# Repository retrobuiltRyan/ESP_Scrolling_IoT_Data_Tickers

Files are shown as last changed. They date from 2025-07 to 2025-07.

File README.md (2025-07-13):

# ESP_Scrolling_IoT_Data_Tickers
ESP8266 (or ESP32) IoT data tickers for news, weather, stocks. For those classic looking 8x8 LED matrix modules. Custom ESP8266 Node MCU 12-E PCB (just bc i have a bunch of these dev boards I need to put to use to toss) with built-in buck converter (6-28V in) and SPI headers. PCB could use one more rev to address some quirks with the ESP8266's strapping pins (rotary encoder), but project is consider 'finished'.  
https://youtu.be/6R5AQ15R8a4

API's used:
api.weather.gov
https://newsapi.org/
finnhub.io

vlcsnap-2025-07-13-12h41m03s127



P1110438

PCB

| Reference | Value | Footprint | Qty | DNP  | DigiKey P/N |
|---|---|---|-----|---|---|
| BZ1 | Buzzer_5V | Buzzer_Beeper:MagneticBuzzer_ProSignal_ABT-410-RC | 1 | DNP | |
| C1,C3,C4,C5,C6 | 0.1uF 50V | Capacitor_SMD:C_1206_3216Metric | 5 | | 1276-1068-1-ND |
| C2,C7 | 0.22uF 50V CER | Capacitor_SMD:C_1206_3216Metric | 2 | | 445-2283-1-ND |
| D8 | D | Diode_SMD:D_SMC_Handsoldering | 1 | DNP  | S5AC-FDICT-ND |
| D9 | SMF15A | Diode_SMD:D_SMF | 1 | | SMF15A-E3-08CT-ND |
| J1 | Barrel_Jack | Connector_BarrelJack:BarrelJack_GCT_DCJ200-10-A_Horizontal | 1 | | EJ508A-ND |
| J2,J5,J6,J10 | Screw_Terminal_2_P3.50mm | TerminalBlock_Phoenix:PT-1,5-2-3.5-H_1x02_P3.50mm_Horizontal | 4 | |732-2747-ND|
| J3 | PINHD_1x5_Male | Connector_PinHeader_2.54mm:PinHeader_1x05_P2.54mm_Vertical | 1 | |  generic 0.1" breakaway header |
| J8 | PINHD_1x15_Male | Connector_PinHeader_2.54mm:PinHeader_1x15_P2.54mm_Vertical | 1 | | generic 0.1" breakaway header |
| Q1 | MOSFET P-CH 30V 25A TO252  | MOSFET_P-CH_30V_25A_TO252 | 1 | | 785-1106-1-ND |
| Q2 | MMBT2222A | Package_TO_SOT_SMD:SOT-23 | 1 | | MMBT2222ATPMSCT-ND |
| R1 | 220 | Resistor_SMD:R_1206_3216Metric | 1 | | 311-220FRCT-ND |
| R2,R3,R5,R6 | 1K | Resistor_SMD:R_1206_3216Metric | 4 | | 311-1.00KFRCT-ND |
| R4 | 3.3K | Resistor_SMD:R_1206_3216Metric | 1 | | 311-1.00KFRCT-ND |
| R7 | 100k | Resistor_SMD:R_1206_3216Metric | 1 | | 311-100KFRCT-ND |
| R8,R9,R10 | 10K | Resistor_SMD:R_1206_3216Metric | 3 | | 311-10.0KFRCT-ND |
| SW1 | RotaryEncoder_Switch_MP | Rotary_Encoder:RotaryEncoder_Alps_EC11E-Switch_Vertical_H20mm | 1 | DNP | PEC11R-4220F-S0024-ND |
| U1 | MAX40200AUK | Package_TO_SOT_SMD:SOT-23-5 | 1 | | 175-MAX40203AUK+TCT-ND |
| U2 | MP1584_Buck | MP1584 | 1 | [Aliexpress](https://www.aliexpress.us/item/3256806890547813.html) |
| U3 | L7805 | Package_TO_SOT_SMD:TO-252-2 | 1 |DNP | 497-7255-1-ND |

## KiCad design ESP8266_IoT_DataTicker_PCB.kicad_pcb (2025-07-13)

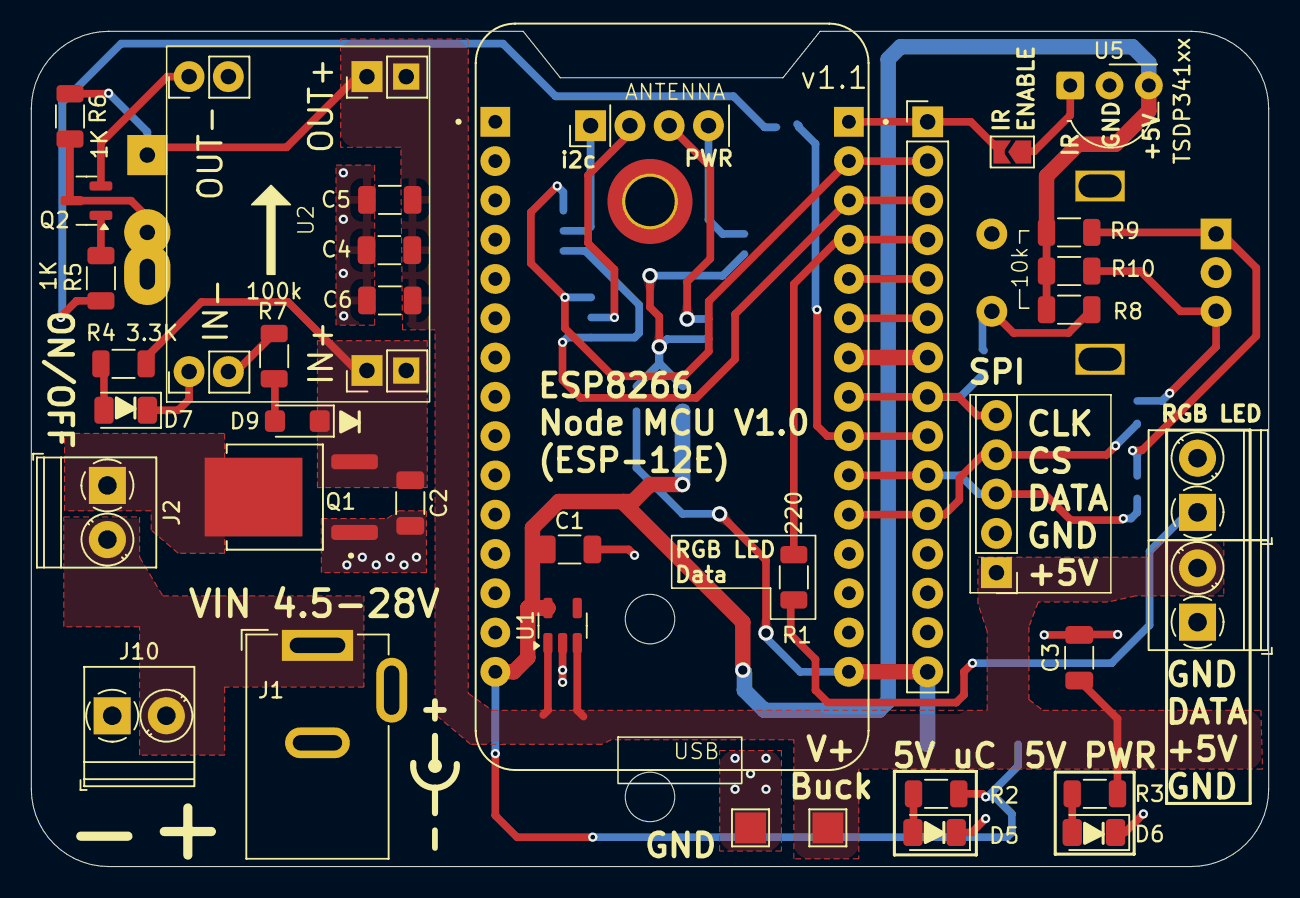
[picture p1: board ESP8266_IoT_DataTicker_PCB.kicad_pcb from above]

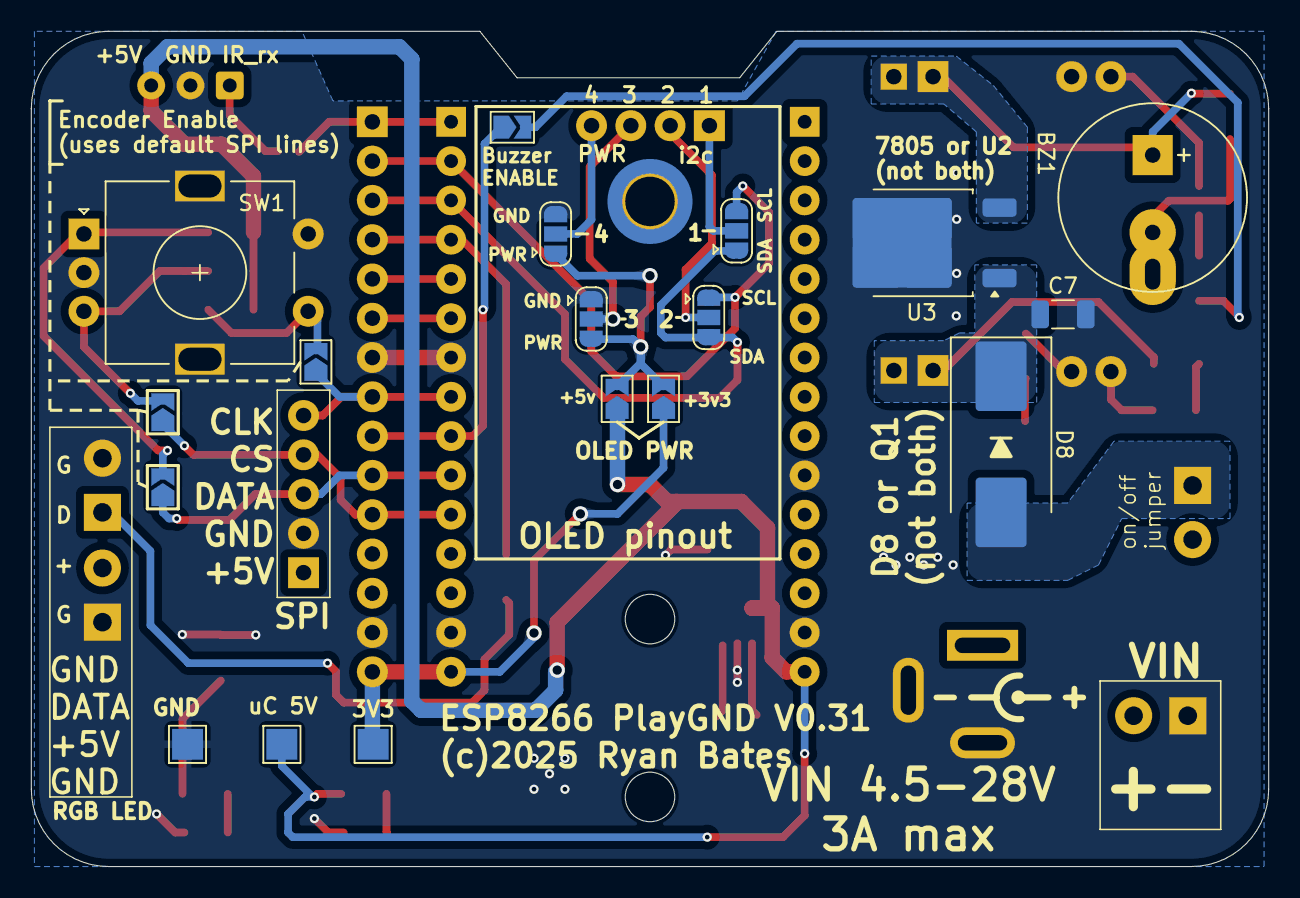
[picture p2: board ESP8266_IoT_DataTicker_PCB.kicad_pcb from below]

Board: 2 copper layers, 80.0 x 54.0 mm, 59 parts (18 on the bottom side), 34 nets.

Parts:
BZ1: Buzzer_5V; MagneticBuzzer_ProSignal_ABT-410-RC
C1, C3, C4, C5, C6: 0.1uF 50V; C_1206_3216Metric
C2, C7: 0.22uF 50V CER; C_1206_3216Metric
D5, D6, D7: LED; LED_1206_3216Metric
D8: D; D_SMC_Handsoldering
D9: SMF15A; D_SMF
H1: MountingHole; MountingHole_3.2mm_M3_ISO14580_Pad_TopBottom
H2, H3: MountingHole_M3; MountingHole_3.2mm_M3
J1: Barrel_Jack; BarrelJack_GCT_DCJ200-10-A_Horizontal
J2, J5, J6, J10: Screw_Terminal_2_P3.50mm; TerminalBlock_Phoenix_PT-1,5-2-3.5-H_1x02_P3.50mm_Horizontal
J3: PINHD_1x5_Male; PinHeader_1x05_P2.54mm_Vertical
J8: PINHD_1x15_Male; PinHeader_1x15_P2.54mm_Vertical
J9: PINHD_1x4_Male; PinHeader_1x04_P2.54mm_Vertical
JP1, JP3, JP5, JP6, JP9, JP10, JP11: SolderJumper_2_Open; SolderJumper-2_P1.3mm_Open_TrianglePad1.0x1.5mm
JP2, JP4, JP7, JP8: SolderJumper_3_Open; SolderJumper-3_P1.3mm_Open_RoundedPad1.0x1.5mm
Q1: MOSFET P-CH 30V 25A TO252; MOSFET_P-CH_30V_25A_TO252
Q2: MMBT2222A; SOT-23
R1: 220; R_1206_3216Metric
R2, R3, R5, R6: 1K; R_1206_3216Metric
R4: 3.3K; R_1206_3216Metric
R7: 100k; R_1206_3216Metric
R8, R9, R10: 10K; R_1206_3216Metric
SW1: RotaryEncoder_Switch_MP; RotaryEncoder_Alps_EC11E-Switch_Vertical_H20mm
TP1, TP3, TP4, TP6: uC +5V; TestPoint_Pad_2.0x2.0mm
TP2: 3V3; TestPoint_Pad_2.0x2.0mm
TP5: TestPoint; PinHeader_1x01_P1.00mm_Vertical
U1: MAX40200AUK; SOT-23-5
U2: MP1584_Buck; MP1584
U3: L7805; TO-252-2
U5: TSDP341xx; Vishay_MOLD-3Pin
v1.1: ESP8266; NodeMCU 12-E

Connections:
+5V_LED: BZ1.1, C3.1, C4.1, C5.1, C6.1, J3.1, J6.2, R3.1, R6.1, TP3.1, U1.1 (VDD), U1.3 (EN), U2.5 (OUT+), U2.6 (OUT+), U3.3 (OUT)
+BATT: J1.1, J2.2, J10.2
/1: J9.1, JP2.2 (C)
/2: J9.2, JP4.2 (C)
/3: J9.3, JP7.2 (C)
/3V3: J8.15, JP6.1 (A), TP2.1, v1.1.16 (3V3)
/4: J9.4, JP8.2 (C)
/BATT_IN: D8.2 (A), J2.1, Q1.2 (S)
/BATT_IN+: C2.1, C7.1, D8.1 (K), D9.1 (A1), Q1.3 (D), R4.1, U2.3 (IN+), U2.4 (IN+), U3.1 (IN)
/Buzzer: JP3.2 (B), R5.1
/D4(GPIO2): J8.5, v1.1.26 (D4)
/D6(GPIO12): J8.9, JP3.1 (A), v1.1.22 (D6)
/Encoder Button: JP11.2 (B), R8.1, SW1.S1
/Encoder CH_A: JP9.2 (B), R9.1, SW1.A
/Encoder CH_B: JP10.2 (B), R10.2, SW1.B
/IR_DATA: JP1.1 (A), U5.1 (OUT)
/PWR: JP5.2 (B), JP6.2 (B), JP7.3 (B), JP8.3 (B)
/RGB_DATA: J8.4, R1.2, v1.1.27 (D3)
/SCL: J8.2, JP2.1 (A), JP4.1 (A), v1.1.29 (D1)
/SDA: J8.3, JP2.3 (B), JP4.3 (B), v1.1.28 (D2)
/SPI_CLK: J3.5, J8.8, JP11.1 (A), v1.1.23 (D5)
/SPI_CS: J3.4, J8.11, JP10.1 (A), v1.1.20 (D8)
/SPI_DATA: J3.3, J8.10, JP9.1 (A), v1.1.21 (D7)
GND: C1.2, C2.2, C3.2, C4.2, C5.2, C6.2, C7.2, D5.1 (K), D6.1 (K), D7.1 (K), J1.2, J3.2, J5.2, J6.1, J8.7, J8.14, J10.1, JP7.1 (A), JP8.1 (A), Q1.1 (G), Q2.2 (E), R7.2, SW1.C, SW1.MP, SW1.S2, TP4.1, TP6.1, U1.2 (GND), U2.1 (IN-), U2.2 (IN-), U2.7 (OUT-), U2.8 (OUT-), U3.2 (GND), U5.2 (GND), v1.1.10 (GND), v1.1.14 (GND), v1.1.17 (GND), v1.1.24 (GND)
MicroContrl_+5V: C1.1, JP5.1 (A), R2.1, R8.2, R9.2, R10.1, TP1.1, U1.5 (OUT), U5.3 (Vs), v1.1.15 (VIN)
unnamed: D5.2 (A), R2.2
unnamed: D6.2 (A), R3.2
unnamed: D7.2 (A), R4.2
unnamed: D9.2 (A2), R7.1
unnamed: J5.1, R1.1
unnamed: J8.6, v1.1.25 (3V3)
unnamed: J8.1, JP1.2 (B), v1.1.30 (D0)
unnamed: Q2.1 (B), R5.2
unnamed: BZ1.2, Q2.3 (C), R6.2, TP5.1

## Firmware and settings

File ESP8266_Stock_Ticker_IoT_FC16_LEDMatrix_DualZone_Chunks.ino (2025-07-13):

/* IoT Stock Price text scroller for ESP8266 | Node MCU V1.0 (ESP-12E) Flash size 4MB, CPU Freq 80MHz
- Fetches 25 real-time stock prices using Finnhub.io (60 calls/minute free API)
- Parses stock data from JSON littered with HTTP messages
- Displays prices on 8x64 LED matrix (MAX72xx) in 2 zones and sorts by gain or loss.
+-------------------------------+
|           Zone 0  (tops)      |  
|    Scrolling stock ↑ gain     | 
+-------------------------------+
|           Zone 1  (bottom)    |  
|   Scrolling stock ↓ loss      | 
+-------------------------------+
- Scrolls stock data with custom up/down arrows
- Uses non-blocking logic to fetch data smoothly
- Separates the upStock and downStock into chunks to avoid overflowing the Parola library scroll buffer. 
-this is a huge pain in the ass to get this working with the Parola hardware. scrolling buffer is max199
characters when using 2 zones, so this code is 2x longer to impliment. (just use the esp32/ and RGB Pmatrix displays)
- Automatically reconnects to WiFi if disconnected
*/

// =========================== WiFi Config =============================
//#define USE_DEVICE_WIFI  // Comment this line to use the second WiFi config
#ifdef USE_DEVICE_WIFI
const char* ssid = "special wifi";
const char* password = "";
#else
const char* ssid = "your wifi name";
const char* password = "you password";
#endif

// =========================== API Config =============================
const char* apiKey = "replace with your Api key";    // Replace with your Finnhub.io API key
const char* finnhubHost = "finnhub.io";
const int httpsPort = 443;

// =========================== Libraries =============================
#include <ESP8266WiFi.h>
#include <WiFiClientSecure.h>
#include <ArduinoJson.h>
#include <MD_Parola.h>
#include <SPI.h>

// =========================== Custom Arrows GFX =============================
const uint8_t downArrow[] = {
  7,  // array/arrow draw is rotated 90deg because the because this hardware is weird
  0b0001000,
  0b0011000,
  0b0111111,
  0b1111111,
  0b0111111,
  0b0011000,
  0b0001000
};

const uint8_t upArrow[] = {
  7,  // also drawn sideways
  0b0001000,
  0b0001100,
  0b1111110,
  0b1111111,
  0b1111110,
  0b0001100,
  0b0001000
};
// #define DEBUG_MODE  // Comment out this line to disable debug output
// =========================== Debug Config =============================
#ifdef DEBUG_MODE
  #define DEBUG_PRINT(x)     Serial.print(x)
  #define DEBUG_PRINTLN(x)   Serial.println(x)
  #define DEBUG_PRINTF(...)  Serial.printf(__VA_ARGS__)
#else
  #define DEBUG_PRINT(x)
  #define DEBUG_PRINTLN(x)
  #define DEBUG_PRINTF(...)
#endif
// =========================== Matrix Config =============================
#define HARDWARE_TYPE MD_MAX72XX::FC16_HW
#define MAX_DEVICES 16 //change this to fit your harware
#define NUM_ZONES 2
#define ZONE_SIZE (MAX_DEVICES / NUM_ZONES)

#define CLK_PIN   D5   //SPI connections
#define DATA_PIN  D7
#define CS_PIN    D8

MD_Parola P = MD_Parola(HARDWARE_TYPE, CS_PIN, MAX_DEVICES);

int scrollSpeed = 25; // Lower is faster

// =========================== Globals =============================
unsigned long lastFetch = 0;
const unsigned long interval = 600000; // 10 minutes then fetch new stock numbers
#define MSG_MAX_LEN 128
char currentMsg[MSG_MAX_LEN] = "Loading stock prices...";
char lastKnownScrollMsg[MSG_MAX_LEN] = "Waiting for data...";

#define MAX_SCROLL_CHUNK 200 //max number of characters in a string chunk
char upChunks[4][MAX_SCROLL_CHUNK];
char downChunks[4][MAX_SCROLL_CHUNK];
int numUpChunks = 0;
int numDownChunks = 0;
int currentChunkIndex = 0;
unsigned long lastChunkTime = 0;
const unsigned long chunkDisplayDuration = 15000; // 15 seconds per chunk


bool newMessage = true;

const char* symbols[] = { // don't fetch more than 25 stocks. API freebie limit is 60 requests per minute. else key will be blocked.
"AAPL", "AMD", "AMZN", "BABA", "CMCSA",
"EA", "GME", "GOOGL", "IBM", "INTC",
"META", "MMM", "MSFT", "NFLX", "NVDA",
"RIVN", "QCOM", "TSLA", "TTWO", "TSM"
};
const int numSymbols = sizeof(symbols) / sizeof(symbols[0]);

unsigned long wifiReconnectLastAttempt = 0;
const unsigned long wifiReconnectInterval = 5000; // try reconnect every 5 seconds
bool wifiReconnecting = false;

// =========================== Setup =============================
void setup() {
  Serial.begin(115200);
  delay(1000);
  Serial.println("System starting...");
  delay(1000);
  P.begin(NUM_ZONES);

  for (uint8_t i = 0; i < NUM_ZONES; i++) {
    P.setZone(i, ZONE_SIZE * i, (ZONE_SIZE * (i + 1)) - 1);
  }

  P.setIntensity(1); // 1=low brightness, 16=max brightness. uses lots of power
  P.setInvert(false); //true = wayyyyyy more power, but kinda neat look, harder to read
  P.setSpeed(scrollSpeed);
  P.setPause(1000);
  P.setTextAlignment(PA_LEFT);

  P.addChar('^', upArrow);   // Use '^' for up
  P.addChar('v', downArrow); // Use 'v' for down

  WiFi.begin(ssid, password);
  Serial.println(WiFi.macAddress()); //cannot call this before WiFi is initialized

  // Displaysomething on boot .
  P.displayText("Connecting...", PA_LEFT, 10, 0, PA_SCROLL_LEFT, PA_SCROLL_LEFT);

  // Wait for WiFi connection but keep animating display and letting WiFi run
  while (WiFi.status() != WL_CONNECTED) {
    P.displayAnimate();
    delay(50); // small delay for WiFi stack and display refresh
    Serial.print(".");
  }
  Serial.println("\nConnected to WiFi!");
  fetchAllStockPrices(); // Initial cache population
}

void loop() {
  unsigned long now = millis();

  // Check WiFi status and attempt reconnect if disconnected
  if (WiFi.status() != WL_CONNECTED) {
    if (!wifiReconnecting) {
      Serial.println("WiFi disconnected, attempting reconnect...");
      wifiReconnecting = true;
      P.displayZoneText(0, "Reconnecting WiFi...", PA_LEFT, scrollSpeed, 0, PA_SCROLL_LEFT, PA_SCROLL_LEFT);
      P.displayZoneText(1, "", PA_LEFT, scrollSpeed, 0, PA_SCROLL_LEFT, PA_SCROLL_LEFT);
      P.displayReset();
    }

    if (now - wifiReconnectLastAttempt >= wifiReconnectInterval) {
      wifiReconnectLastAttempt = now;
      WiFi.disconnect();
      WiFi.reconnect();
      Serial.println("Reconnecting to WiFi...");
    }

    P.displayAnimate();
    delay(10);

    // RETURN EARLY to skip normal operation when disconnected
    return;
  } else {
    if (wifiReconnecting) {
      Serial.println("WiFi reconnected!");
      wifiReconnecting = false;
      lastFetch = 0;
      scrollText("WiFi connected, fetching stock prices...");
    }
  }

  // Animate both zones
  P.displayAnimate();

  // Rotate through up/down chunks every 15 seconds
  if ((numUpChunks > 1 || numDownChunks > 1) && millis() - lastChunkTime >= chunkDisplayDuration) {
    currentChunkIndex++;
    if (currentChunkIndex >= max(numUpChunks, numDownChunks)) {
      currentChunkIndex = 0;
    }

    if (currentChunkIndex < numUpChunks) {
      P.displayZoneText(1, upChunks[currentChunkIndex], PA_LEFT, scrollSpeed, 1000, PA_SCROLL_LEFT, PA_SCROLL_LEFT);
      P.displayReset(1);
    }

    if (currentChunkIndex < numDownChunks) {
      P.displayZoneText(0, downChunks[currentChunkIndex], PA_LEFT, scrollSpeed, 1000, PA_SCROLL_LEFT, PA_SCROLL_LEFT);
      P.displayReset(0);
    }

    lastChunkTime = millis();
  }

  // Restart scrolling when both zones finish
  if (P.getZoneStatus(0) && P.getZoneStatus(1)) {
    P.displayReset(0);
    P.displayReset(1);
  }

  // Refresh quotes every 10 minutes
  if (now - lastFetch >= interval || lastFetch == 0) {
    Serial.println("\nFetching all stock prices...");
    fetchAllStockPrices();
    lastFetch = now;
  }

  if (newMessage) { //maybe this helps, i doubt it
    Serial.println("Resetting display zones...");
    P.displayReset(0);
    P.displayReset(1);
    newMessage = false;
  }
}


// =========================== Scroll Update ==================================
void scrollText(const char* p) {
  strncpy(currentMsg, p, sizeof(currentMsg) - 1);
  newMessage = true;
}

// =========================== Symbol Mapping Helper ====================================
const char* symbolToQuery(const char* sym) {
  if (strcmp(sym, "BRK.B") == 0) return "BRKB";
  return sym;
}

// =========================== Fetch SINGLE Stock ========================================
bool fetchSingleStockPrice(const char* symbol, String &result) {
  WiFiClientSecure client;
  client.setInsecure();  // Warning: insecure mode used for simplicity

  String querySymbol = symbolToQuery(symbol);
  String path = "/api/v1/quote?symbol=" + String(querySymbol) + "&token=" + apiKey;

  if (!client.connect(finnhubHost, httpsPort)) {
    Serial.printf("Connection failed for %s\n", symbol);
    return false;
  }

  // Send HTTP GET request
  client.print(String("GET ") + path + " HTTP/1.1\r\n" +
               "Host: " + finnhubHost + "\r\n" +
               "User-Agent: ESP8266\r\n" +
               "Connection: close\r\n\r\n");

  // Read status line
  String statusLine = client.readStringUntil('\n');
  statusLine.trim();
  //Serial.println("Status Line: " + statusLine); debug, checking if the API is happy with the request HTTP 200 is good
  if (!statusLine.startsWith("HTTP/1.1 200")) {
    Serial.println("HTTP error or unexpected status");
    return false;
  }

  // Skip headers safely
  int headerLines = 0;
  while (true) {
    String headerLine = client.readStringUntil('\n');
    headerLine.trim();
    //Serial.println("Header: " + headerLine); //debug stuff
    headerLines++;

    if (headerLine.length() == 0) {
      //Serial.println("End of headers after " + String(headerLines) + " lines."); //debug stuff
      break;
    }

    if (headerLines > 30) {
      Serial.println("Too many headers, aborting.");
      return false;
    }
  }

  // Read JSON payload with timeout
  String payload = "";
  unsigned long timeout = millis() + 5000; // 5 second timeout
  while (millis() < timeout) {
    while (client.available()) {
      char c = client.read();
      payload += c;
      timeout = millis() + 5000;  // Reset timeout on every byte
    }
    if (payload.length() > 0) break;
    delay(10); // Prevent busy wait
  }

  payload.trim();
  //Serial.println("Payload received: \"" + payload + "\""); //debug

  if (payload.length() == 0) {
    Serial.printf("JSON error for %s: EmptyInput\n", symbol);
    return false;
  }

  // Parse JSON
  StaticJsonDocument<1024> doc;
  DeserializationError err = deserializeJson(doc, payload);
  if (err) {
    Serial.printf("JSON error for %s: %s\n", symbol, err.c_str());
    return false;
  }

  if (doc.containsKey("error")) {
    Serial.printf("API error for %s: %s\n", symbol, doc["error"].as<const char*>());
    return false;
  }

  if (!doc.containsKey("c") || doc["c"].isNull()) {
    Serial.printf("Invalid data for %s: missing 'c'\n", symbol);
    return false;
  }

  // Extract and format result
  float current = doc["c"];
  float change = doc["d"];
  float percent = doc["dp"];

  String arrow = (change >= 0) ? "^" : "v";
  String percentSign = (percent >= 0) ? "+" : "";
  String changeSign = (change >= 0) ? "+" : "";

  result = String(symbol) + ": $" + String(current, 2) + " " + arrow
           + " " + changeSign + String(change, 2) + " (" + percentSign + String(percent, 2) + " % )   ";
  
  Serial.println(result);
  return true;
}

// =========================== Fetch All Stock Prices =============================
//to fit within the API's freebie limits what happens here is not "efficient" but does the job without getting blocked from the API
//Sends an HTTP GET request for that one symbol
//Waits for and reads the response JSON payload
//Parses and formats that data into a display string

// =========================== Fetch All Stock Prices =============================
void fetchAllStockPrices() {
  String upStocks = "";
  String downStocks = "";
  bool success = false;

  for (int i = 0; i < numSymbols; i++) {
    String stockMsg;
    const char* sym = symbols[i];

    if (fetchSingleStockPrice(sym, stockMsg)) {
      success = true;
      if (stockMsg.indexOf('^') >= 0) {
        upStocks += stockMsg;
        upStocks += "     ";
      } else {
        downStocks += stockMsg;
        downStocks += "     ";
      }
    } else {
      downStocks += String(sym) + ": N/A       ";
    }

    delay(780);
    //toggle serial print for size of string length when building the gain and loss stock strings 
    DEBUG_PRINT("upStocks / downStocks length: ");
    DEBUG_PRINT(upStocks.length()); DEBUG_PRINT(" / "); DEBUG_PRINT(downStocks.length());
    DEBUG_PRINT("   Free heap: ");
    DEBUG_PRINTLN(ESP.getFreeHeap());
  }

  if (success) {
    upStocks.trim();
    downStocks.trim();

    // Chunk upStocks manually, breaking on complete stock messages
    numUpChunks = 0;
    int upLen = upStocks.length();
    int upStart = 0;
    String upChunk = "";
    while (upStart < upLen && numUpChunks < 4) {
      int nextSpace = upStocks.indexOf("     ", upStart);
      if (nextSpace == -1) nextSpace = upLen;

      String stockEntry = upStocks.substring(upStart, nextSpace + 5); // include 5-space delimiter
      if (upChunk.length() + stockEntry.length() >= MAX_SCROLL_CHUNK - 1) {
        upChunk.toCharArray(upChunks[numUpChunks], MAX_SCROLL_CHUNK);
        upChunks[numUpChunks][MAX_SCROLL_CHUNK - 1] = '\0';
        Serial.println("=============Chunk Formation==============");
        Serial.print("Up Chunk "); Serial.print(numUpChunks); Serial.print(": ");
        Serial.println(upChunks[numUpChunks]);
        numUpChunks++;
        upChunk = "";
        if (numUpChunks >= 4) break;
      }
      upChunk += stockEntry;
      upStart = nextSpace + 5;
    }

    if (upChunk.length() > 0 && numUpChunks < 4) {
      upChunk.toCharArray(upChunks[numUpChunks], MAX_SCROLL_CHUNK);
      upChunks[numUpChunks][MAX_SCROLL_CHUNK - 1] = '\0';
      Serial.println("=============Chunk Formation==============");
      Serial.print("Up Chunk "); Serial.print(numUpChunks); Serial.print(": ");
      Serial.println(upChunks[numUpChunks]);
      numUpChunks++;
    }

    // Chunk downStocks manually, breaking on complete stock messages
    numDownChunks = 0;
    int downLen = downStocks.length();
    int downStart = 0;
    String downChunk = "";
    while (downStart < downLen && numDownChunks < 4) {
      int nextSpace = downStocks.indexOf("     ", downStart);
      if (nextSpace == -1) nextSpace = downLen;

      String stockEntry = downStocks.substring(downStart, nextSpace + 5); // include 5-space delimiter
      if (downChunk.length() + stockEntry.length() >= MAX_SCROLL_CHUNK - 1) {
        downChunk.toCharArray(downChunks[numDownChunks], MAX_SCROLL_CHUNK);
        downChunks[numDownChunks][MAX_SCROLL_CHUNK - 1] = '\0';
        Serial.println("=============Chunk Formation==============");
        Serial.print("Down Chunk "); Serial.print(numDownChunks); Serial.print(": ");
        Serial.println(downChunks[numDownChunks]);
        numDownChunks++;
        downChunk = "";
        if (numDownChunks >= 4) break;
      }
      downChunk += stockEntry;
      downStart = nextSpace + 5;
    }

    if (downChunk.length() > 0 && numDownChunks < 4) {
      downChunk.toCharArray(downChunks[numDownChunks], MAX_SCROLL_CHUNK);
      downChunks[numDownChunks][MAX_SCROLL_CHUNK - 1] = '\0';
      Serial.println("=============Chunk Formation==============");
      Serial.print("Down Chunk "); Serial.print(numDownChunks); Serial.print(": ");
      Serial.println(downChunks[numDownChunks]);
      numDownChunks++;
    }

    currentChunkIndex = 0;
    lastChunkTime = millis();

    // Load first chunk into zones
    P.displayZoneText(1, upChunks[currentChunkIndex], PA_LEFT, scrollSpeed, 1000, PA_SCROLL_LEFT, PA_SCROLL_LEFT);
    P.displayZoneText(0, downChunks[currentChunkIndex], PA_LEFT, scrollSpeed, 1000, PA_SCROLL_LEFT, PA_SCROLL_LEFT);
    newMessage = true;
    strncpy(lastKnownScrollMsg, currentMsg, sizeof(lastKnownScrollMsg) - 1);
  } else {
    Serial.println("Fetch failed — using cached data.");
    strncpy(currentMsg, lastKnownScrollMsg, sizeof(currentMsg) - 1);
    newMessage = true;
  }
}

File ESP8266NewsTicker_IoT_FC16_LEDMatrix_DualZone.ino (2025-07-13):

/*IoT Weather forcast and News headline text scroller for ESP8266 Node MCU V1.0 (ESP-12E) Flash size 4MB, CPU Freq 80MHz
Grabs forcast from api.weather.gov (free to use API without key, USA only)
Grabs news from newsapi.org (requires API key). Free API use has 100 request/day limit
Outputs all web data to serial for debugging or big chunk to output to other display type.

Hardware is 16x of FC16_HW LED matrix (SPI communication) split into 2 zones.
ESP32 also works (better) but I am trying to use some old hardware/parts
Requires external power (2-3A @5v) for the MAX72xx LED Matrix
released: June 23 2025, Ryan Bates
Compatible hardware is ESP8266 ScoreBoard PCB
*/

// WiFi credentials
const char* ssid = "your wifi ssid 2.4";
const char* password = "your password";
// API credentials
const char* apiKey = "your api key";  // Replace with your NewsAPI key

#include <ESP8266WiFi.h> //change this library if using ESP32
#include <ESP8266HTTPClient.h> //change this library if using ESP32
#include <WiFiClientSecure.h>
#include <ArduinoJson.h>
#include <MD_Parola.h>
//#include <MD_MAX72xx.h> //not using this for LED matrix display
#include <SPI.h>

// ========== Display Config ==========
#define HARDWARE_TYPE MD_MAX72XX::FC16_HW //this may change for your hardware
#define MAX_DEVICES 16
#define NUM_ZONES   2
#define ZONE_SIZE (MAX_DEVICES / NUM_ZONES)
//SPI hardware pins
#define CLK_PIN   D5
#define DATA_PIN  D7
#define CS_PIN    D8

#define SPEED_TIME  25
#define PAUSE_TIME  1000

MD_Parola P = MD_Parola(HARDWARE_TYPE, CS_PIN, MAX_DEVICES);
WiFiClientSecure client;

// ========== News Globals ==========
unsigned long lastNewsFetch = 0;
const unsigned long NEWS_INTERVAL = 3600000; //refresh news every 1 hour
String headlines[10] = {
  "Loading headlines...", "", "", "", "", "", "", "", "", ""
};
uint8_t curHeadline = 0; //what does this do?

// ========== Weather Globals ========== //not used, but could be
unsigned long lastWeatherFetch = 0;
const unsigned long WEATHER_INTERVAL = 3600000; //refresh weather every 1 hour
String forecastMessage = "Loading weather forecast...";
uint8_t curForecastZone = 1;

// ========== Setup ==========
void setup() {
  Serial.begin(115200);
  delay(1000);

  // Matrix setup
  P.begin(NUM_ZONES);
  for (uint8_t i = 0; i < NUM_ZONES; i++) {
    P.setZone(i, ZONE_SIZE * i, ZONE_SIZE * (i + 1) - 1);
  }
  P.setIntensity(1); // 1=low brightness, 16=max brightness. uses lots of power
  P.setInvert(false); //true = wayyyyyy more power, but kinda neat look, harder to read

//===========pushing the hardware MAC address to the screen for posterity==================== can delete this section if you want
  String macStr = WiFi.macAddress(); //get MAC as a string
  static char macChar[20]; //store mac as array and make it static (retain value between function calls, stays forver after void setup)
  macStr.toCharArray(macChar, sizeof(macChar));
  P.displayZoneText(0, "Connecting to WiFi...", PA_CENTER, SPEED_TIME, PAUSE_TIME, PA_SCROLL_LEFT, PA_SCROLL_LEFT);
  P.displayZoneText(1, macChar, PA_CENTER, SPEED_TIME, PAUSE_TIME, PA_SCROLL_LEFT, PA_SCROLL_LEFT);
  P.displayReset();

  unsigned long start = millis(); //special non locking coop to run the matrix during setup and avoid a crash on boot
  while (!P.getZoneStatus(0) || !P.getZoneStatus(1)) {
    P.displayAnimate();
    delay(10);
    yield();  // 🧠 Prevent watchdog reset. special to the ESP8266; i dont understand this hardware
  }



  //  WiFi connect===================================================================================
  WiFi.begin(ssid, password);
  Serial.print("Connecting to WiFi");
  while (WiFi.status() != WL_CONNECTED) {
    delay(500);
    Serial.print(".");
  }
  Serial.print("MAC: "); 
  Serial.println(WiFi.macAddress()); //delete for enteprise security, helpful for network troubleshooting
  delay(1000);
  Serial.println("\n✅ WiFi connected!");
  P.displayZoneText(0, "Wifi connected!", PA_CENTER, SPEED_TIME, PAUSE_TIME, PA_SCROLL_LEFT, PA_SCROLL_LEFT);
  P.displayZoneText(1, "Fetching News!", PA_CENTER, SPEED_TIME, PAUSE_TIME, PA_SCROLL_LEFT, PA_SCROLL_LEFT);
  client.setInsecure();  // Skip cert validation
  
  fetchHeadlines(); // newsapi
  fetchForecast();  //weather.gov
  printStatusToSerial(); // <-- Optional for startup
}

// ========== Loop ==========
void loop() {
  checkWiFiConnection(); //re-establish wifi connection if dropped

  unsigned long now = millis();
 //checks to refresh news and weather
  if (now - lastNewsFetch >= NEWS_INTERVAL || now < lastNewsFetch) {
    fetchHeadlines();
    lastNewsFetch = now;
  }

  if (now - lastWeatherFetch >= WEATHER_INTERVAL || now < lastWeatherFetch) {
    fetchForecast();
    lastWeatherFetch = now;
  }

  // ===================Display News on Zone 0===============================================================
  static bool displayingNews = false;
  if (!displayingNews && P.getZoneStatus(0)) {
    P.displayZoneText(0, headlines[curHeadline].c_str(), PA_CENTER, SPEED_TIME, PAUSE_TIME, PA_SCROLL_LEFT, PA_SCROLL_LEFT);
    displayingNews = true;
  }

  //=================== Display Forecast on Zone 1================================================================
  static bool displayingWeather = false;
  if (!displayingWeather && P.getZoneStatus(curForecastZone)) {
    P.displayZoneText(curForecastZone, forecastMessage.c_str(), PA_CENTER, SPEED_TIME, PAUSE_TIME, PA_SCROLL_LEFT, PA_SCROLL_LEFT);
    displayingWeather = true;
  }

  if (P.displayAnimate()) {
    curHeadline = (curHeadline + 1) % 10;
    displayingNews = false;
    displayingWeather = false;
  }
}

// ========== Sanitize Headlines ==========
//need to remove some special/fancy characters that the parola library cannot display
String sanitizeHeadline(String input) {
  input.replace("’", "'"); input.replace("‘", "'");
  input.replace("“", "\""); input.replace("”", "\"");
  input.replace("—", "-"); input.replace("–", "-");
  input.replace("…", "..."); input.replace("•", "-");
  input.replace("é", "e"); input.replace("á", "a");
  input.replace("ó", "o");
  return input;
}
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

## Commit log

2025-07-13 vector files (laser cutter)
2025-07-13 kiCAD design files
    [ESP8266_IoT_DataTicker_PCB.kicad_pcb, ESP8266_IoT_DataTicker_PCB.kicad_sch]

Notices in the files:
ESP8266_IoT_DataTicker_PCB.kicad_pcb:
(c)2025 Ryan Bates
